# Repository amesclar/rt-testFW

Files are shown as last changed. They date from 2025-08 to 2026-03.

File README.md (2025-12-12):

# Sailing Regatta Timer - Automated Test Framework

- [Sailing Regatta Timer - Automated Test Framework](#sailing-regatta-timer---automated-test-framework)
  - [Key Features](#key-features)
  - [Measuring 12v](#measuring-12v)
  - [Flow Diagram](#flow-diagram)
  - [Board and Wiring](#board-and-wiring)
    - [Schematic](#schematic)
    - [PCB](#pcb)

## Key Features

- automated routine that exercises sailing regatta timer while monitoring buzzer activation (horn voltage)
- test board connected to computer that monitors serial port
- measures and logs horn voltage

## Measuring 12v

```text
V_out = V_in × (R2 / (R1 + R2))

R1 = 10kΩ
R2 = 5k1
```

Ratio: 2:1 (divides voltage by 3)
Output at 12V input: 4V

## Flow Diagram

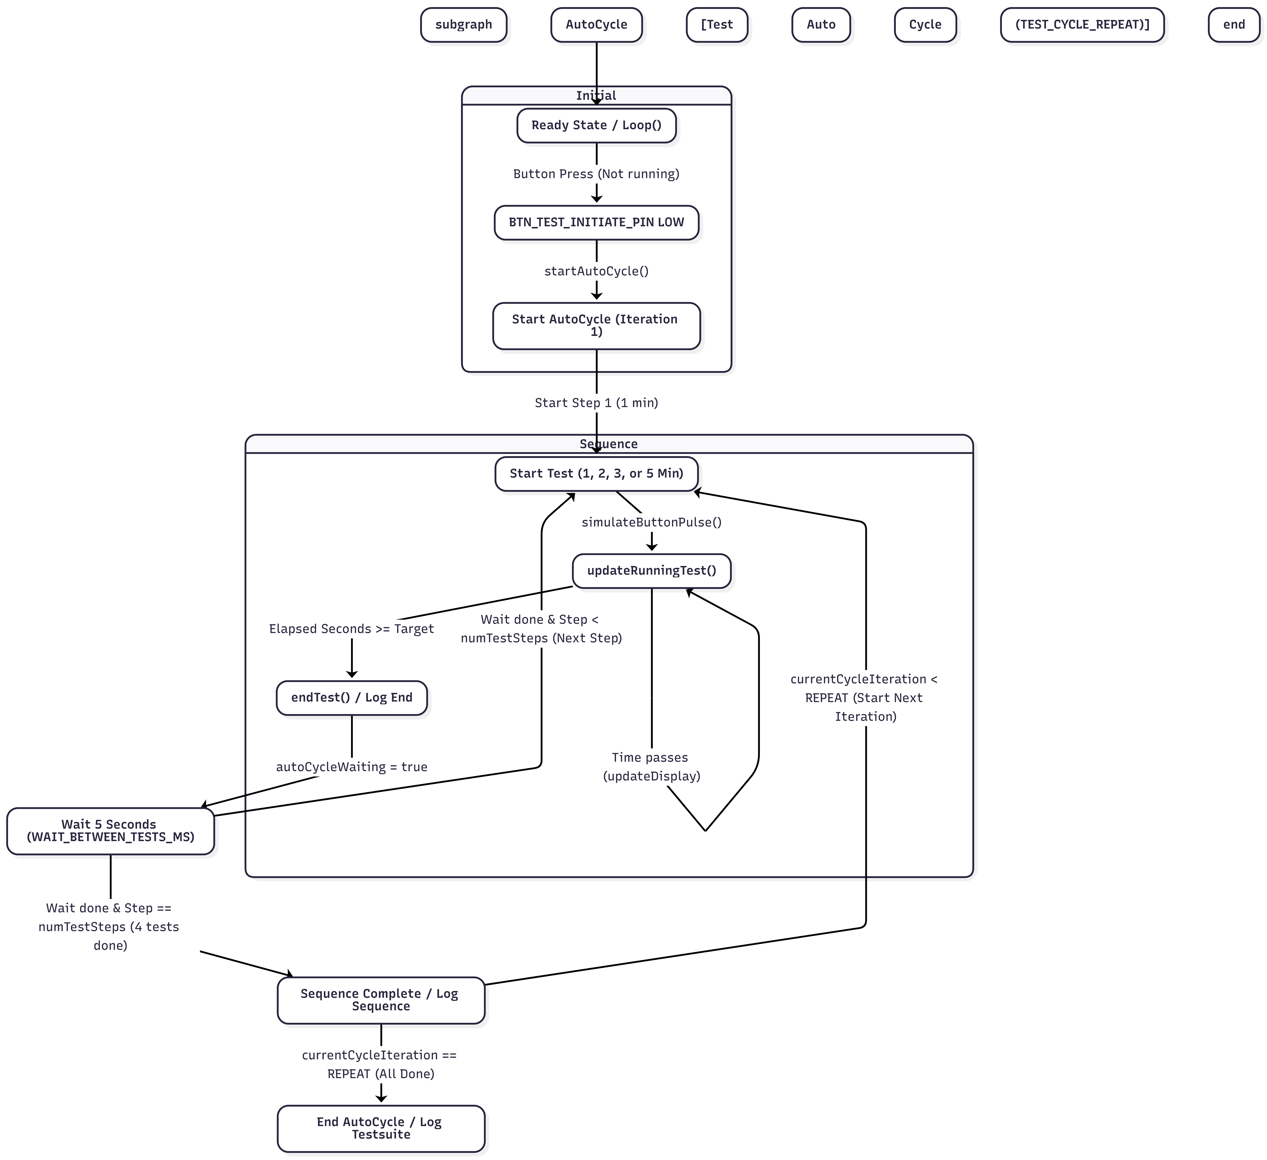
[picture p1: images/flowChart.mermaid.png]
Flow Diagram


## Board and Wiring

### Schematic

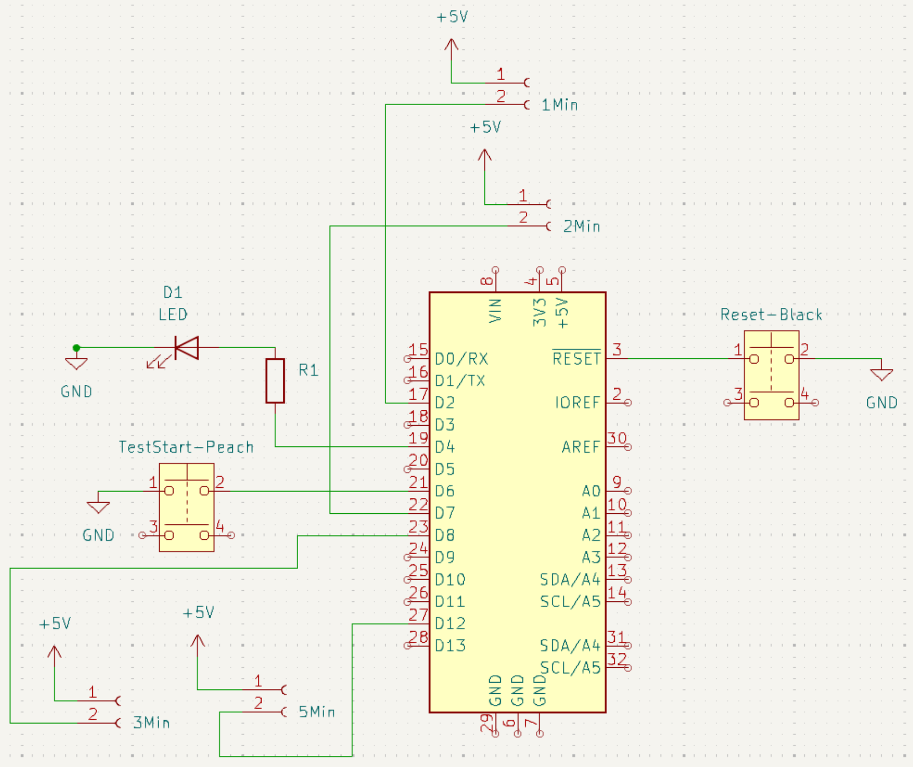
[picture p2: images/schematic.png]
Schematic


### PCB

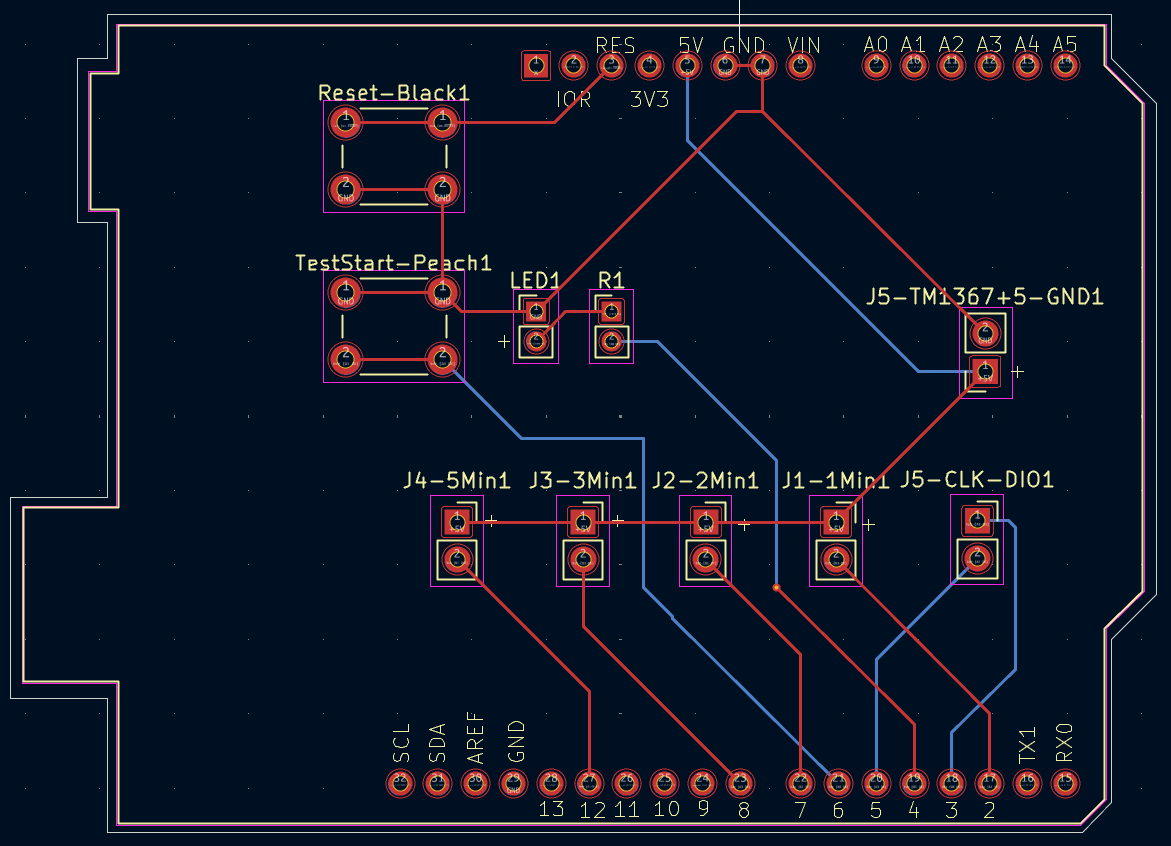
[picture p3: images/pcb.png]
PCB


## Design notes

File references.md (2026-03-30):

# References

## cli board upload

```bash

arduino-cli compile --upload -p /dev/ttyACM0 --fqbn arduino:avr:uno .
```

## dialout group (Linux)

To fix "Permission Denied" errors on serial ports:

```bash
sudo usermod -aG dialout $USER
```

*Note: You must log out and back in for this to take effect.*

### Immediate effect (current terminal only)

```bash
newgrp dialout
```

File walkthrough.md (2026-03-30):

# Walkthrough - Regatta Timer Fixes

The Regatta Timer has been updated to fix the issue where the 1-minute sequence would start automatically upon reset and run continuously. The problem was rooted in incorrect pin configuration and logic levels that didn't match the hardware and technical specifications.

## Changes Made

### 1. Pin Configuration
- Changed `pinMode` for all button pins from `INPUT` to `INPUT_PULLUP`.
- This ensures the pins are tied to 5V (logical `HIGH`) when the button is not pressed, preventing floating inputs that cause random triggers.

### 2. Button Logic Inversion
- Inverted the button press detection logic from `HIGH` to `LOW`.
- Since we are using internal pull-ups, pressing the button connects the pin to ground, resulting in a `LOW` signal.

### 3. Edge Detection
- Re-implemented state tracking using `lastBtn1`, `lastBtn2`, etc.
- The code now looks for a transition from `HIGH` (not pressed) to `LOW` (pressed).
- This ensures the system **waits for a button push** after reset and won't restart a sequence until the button is released and pressed again.

### 4. Specification Alignment
- Increased the software debounce time from 50ms to **200ms** as required by the technical specification.

## Code Comparison

```diff
-  pinMode(PIN_BTN_1MIN, INPUT);
+  pinMode(PIN_BTN_1MIN, INPUT_PULLUP);
```

```diff
-  if (btn1 == HIGH) {
-    delay(50); // Debounce
-    if (digitalRead(PIN_BTN_1MIN) == HIGH) {
+  if (lastBtn1 == HIGH && btn1 == LOW) {
+    delay(200); // Debounce
+    if (digitalRead(PIN_BTN_1MIN) == LOW) {
```

## Verification Results

### Automated Check
The code structure now correctly handles the `INPUT_PULLUP` and edge detection. The addition of state updates after the blocking `runSequence()` calls ensures that the system is ready for the next press immediately after a sequence ends, but only if the button is released first.

### Recommended Manual Tests
1. **Power On**: Verify display shows `00:00` and buzzer remains silent.
2. **Press 1min**: Verify sequence starts.
3. **Hold 1min**: Verify sequence runs once and stops, waiting for release.

---

### Previous Framework Updates
- **Output Idle State**: Output pins now idle at `HIGH` so they don't hold the SUT's `INPUT_PULLUP` pins at `LOW` by default.
- **Pulse Logic**: The `simulateButtonPulse()` function now pulses `LOW` to simulate a button press and then returns to `HIGH` after 400ms.
- **Initialization**: Updated `setup()` to set pins `HIGH` before enabling them as outputs.

---

## Responsiveness & Wiring Guidance

To ensure the system feels fast and reliable, the following timing adjustments and wiring fixes were identified:

### 1. Timing Adjustments
- **Reduced Debounce (SUT & Tester)**: Lowered from 200ms to **50ms**. This makes the buttons feel "snappy" and ensures quick manual taps are not ignored.
- **Increased Pulse Duration (Tester)**: Raised from 200ms to **400ms**. This guarantees that the Regatta Timer has enough time to detect the pulse, even with its own debouncing logic.

### 2. Physical Wiring Fix
The Regatta Timer is now configured for **Active LOW** logic with **Internal Pull-ups**.
- **Button Side**: One side of the button should go to the Pin (e.g., Pin 2) and the **other side should go to GND**, not 5V.
- **Tester Side**: **Tester GND** must be connected to **SUT GND** for the pulse signal to work.

---

## Test Framework Updates (`rt-testFW.ino`)

The test framework has also been adjusted to match the Active LOW configuration of the Regatta Timer.

### Changes Made
- **Output Idle State**: Output pins now idle at `HIGH` so they don't hold the SUT's `INPUT_PULLUP` pins at `LOW` by default.
- **Pulse Logic**: The `simulateButtonPulse()` function now pulses `LOW` to simulate a button press and then returns to `HIGH`.
- **Initialization**: Updated `setup()` to set pins `HIGH` before enabling them as outputs.

### Code Comparison (Tester)
```diff
-  digitalWrite(pin, HIGH);
-  delay(BUTTON_PULSE_DURATION_MS);
-  digitalWrite(pin, LOW);
+  digitalWrite(pin, LOW);
+  delay(BUTTON_PULSE_DURATION_MS);
---

## Baud Rate & Duration Drift Fix (2026-03-25)

The system was updated to synchronize communication at 115200 baud and minimize duration drift in longer tests.

### Changes Made
1. **Baud Rate**: Synchronized Test FW, SUT, and Serial Monitor to **115200 baud** using a consistent `BAUD_RATE` definition.
2. **Validation Reporting**: Improved `rt_data_validation.py` to extract iteration data from the test framework's logs, ensuring error messages align with the specific test sequence being run.

---

## Scrum-73: Voltage Monitoring Fix (2026-03-28)

Resolved the issue where output voltage was not being logged by addressing blocking delays and PWM signal oscillations.

### Changes Made
1. **Non-Blocking Button Pulse**: Replaced `delay(400)` with a non-blocking timer in `startButtonPulse()` and `handleButtonPulse()`. This ensures continuous voltage monitoring.
2. **Voltage Debouncing**: Added a 50ms hold-time (`VOLTAGE_HOLD_DURATION_MS`) to bridge the gaps in PWM-driven buzzer signals.
3. **Proactive Logging**: Added `VoltageStart` logging to capture the beginning of events even if the system resets during the buzzer activation.

- **5V Stimulus Test**: **PASSED**. A0 Raw jumped to ~344.
- **9V Battery Test**: **PASSED**. Connecting a 9V battery directly to the male connector pins resulted in an `A0 Raw` of **617-620** and a consistent `<testcase type="VoltageStart"/>` log.
- **Definitive Conclusion**: The Test Framework hardware, voltage divider, and software monitoring logic are **100% verified and functional**. The lack of logs during normal operation is exclusively due to the **SUT-side hardware fault** (Relay COM shorted to Ground).
- **Compilation**: Successfully compiled using `arduino-cli compile --fqbn arduino:avr:uno .`.

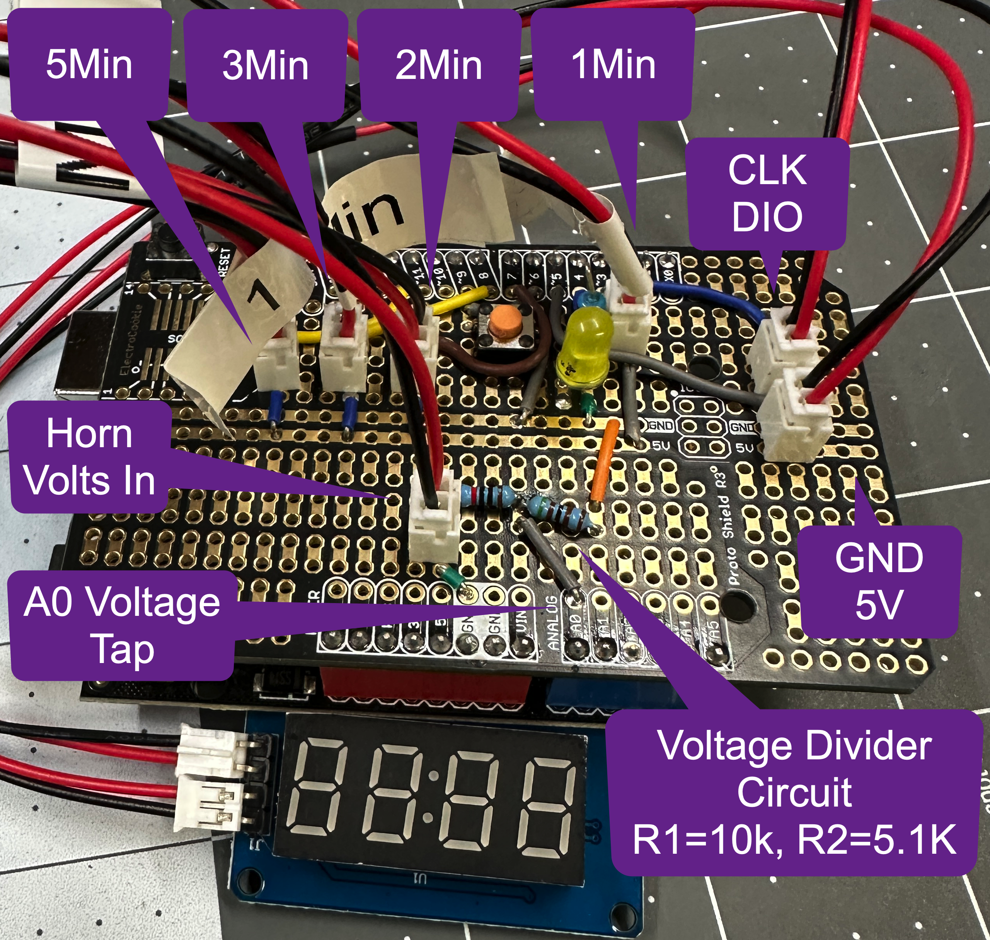
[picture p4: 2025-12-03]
images/circuitBoardProto.png

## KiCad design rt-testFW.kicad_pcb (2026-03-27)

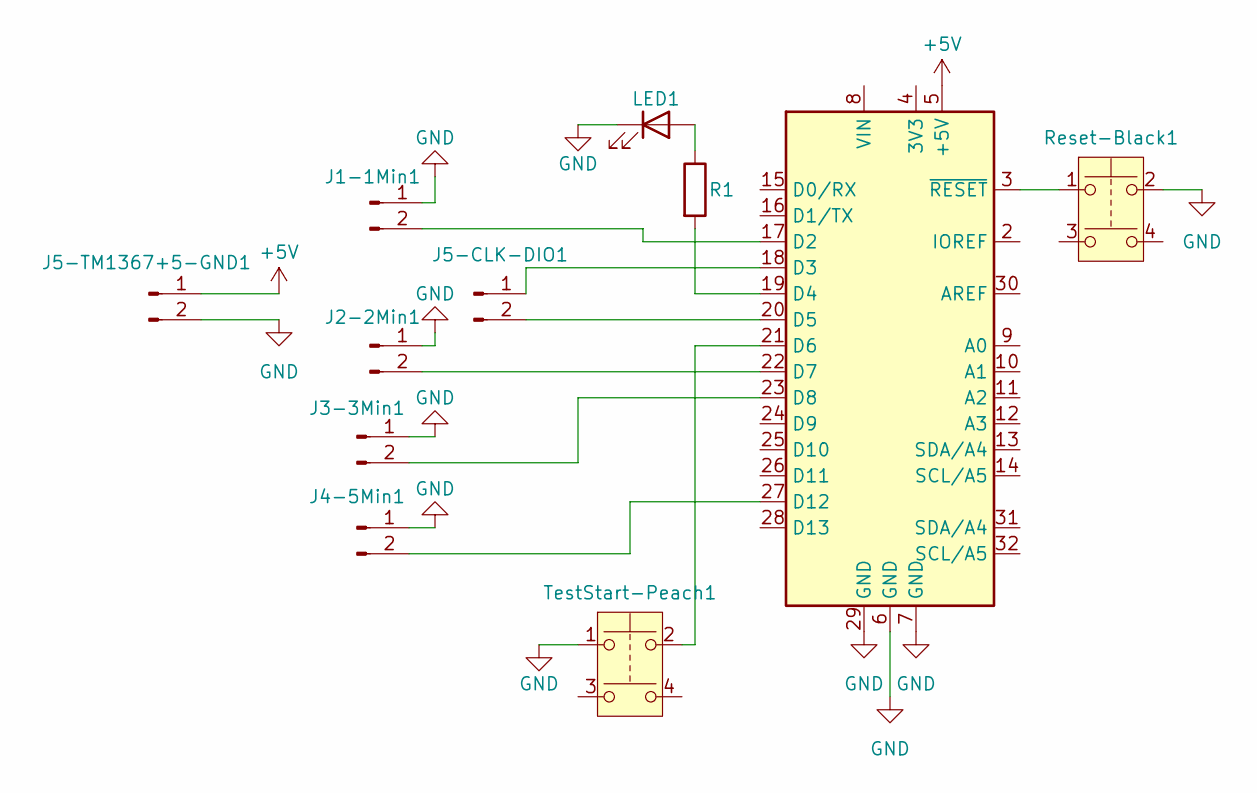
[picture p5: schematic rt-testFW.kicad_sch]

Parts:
A1: Arduino_UNO_R3
J1-1Min1, J2-2Min1, J3-3Min1, J4-5Min1, J5-CLK-DIO1, J5-TM1367+5-GND1: Conn_01x02_Male; PinSocket_1x02_P2.54mm_Vertical
LED1: LED; PinHeader_1x02_P2.00mm_Vertical
R1: R; PinHeader_1x02_P2.00mm_Vertical
Reset-Black1: SW_Push_Dual; SW_PUSH_6mm
TestStart-Peach1: SW_Push_Dual; SW_PUSH_6mm

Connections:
+5V: A1.5 (+5V), J5-TM1367+5-GND1.1
GND: A1.6 (GND), A1.7 (GND), A1.29 (GND), J1-1Min1.1, J2-2Min1.1, J3-3Min1.1, J4-5Min1.1, J5-TM1367+5-GND1.2, LED1.1 (K), Reset-Black1.2, TestStart-Peach1.1
unnamed: A1.17 (D2), J1-1Min1.2
unnamed: A1.18 (D3), J5-CLK-DIO1.1
unnamed: A1.19 (D4), R1.2
unnamed: A1.20 (D5), J5-CLK-DIO1.2
unnamed: A1.21 (D6), TestStart-Peach1.2
unnamed: A1.22 (D7), J2-2Min1.2
unnamed: A1.23 (D8), J3-3Min1.2
unnamed: A1.27 (D12), J4-5Min1.2
unnamed: A1.3 (~RESET), Reset-Black1.1
unnamed: LED1.2 (A), R1.1

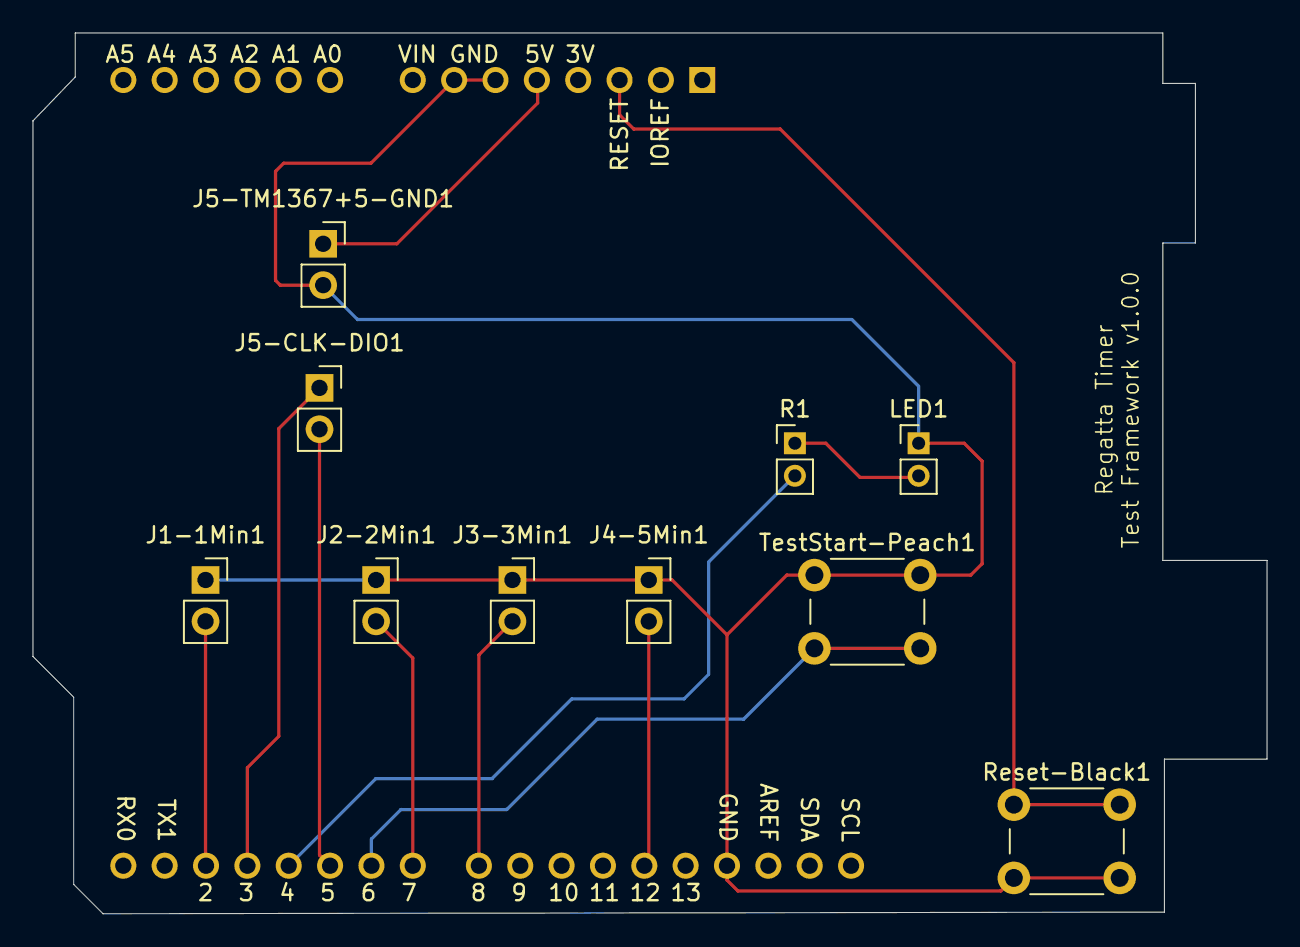
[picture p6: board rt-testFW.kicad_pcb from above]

Board: 2 copper layers, 75.8 x 54.1 mm, 11 parts (0 on the bottom side), 12 nets.

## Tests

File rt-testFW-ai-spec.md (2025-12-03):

# Regatta Timer Test Framework - Technical Specification

## Purpose
This test framework exercises the Sailing Regatta Timer by simulating button presses. Log messages are emitted for overall start, each test start and overall end. The overall test sequence is started upon button press on pin 6. A single test sequnce consists of activating the regatta timer for 1min, 2min, 3min, and 5min sequences with 5 second pause between tests. The test sequence is repeated TEST_CYCLE_REPEAT times with a default of 10.

Continuous horn voltage measurement is made on port A0 with log messages emitted when the voltage exceeds 2V. The log message should contain elapsed time (seconds), peak voltage value and duration of voltage >2V. Ignore durations shorter than 10ms. Voltage elapsed time should reset for each test (1m, 2m, 3m, 5m). The voltage split circuit consists of R1=10k ohm and R2=5.1k ohm.

TM1637 should display countdown time in MM:SS format.

Serial port speed is 9600baud.

Log messages should be JUNIT XML.

## Hardware Components

### Display
- **Type**: TM1637 4-digit 7-segment display
- **CLK Pin**: 3
- **DIO Pin**: 5
- **Format**: MM:SS (minutes:seconds with colon separator)
- **Brightness**: Maximum (0x0f)

### Monitoring Inputs
| Component | Pin | Purpose | Input type |
|---|-----|---| --- |
| Test Cycle Button | 6 | Initiate automated test cycle | INPUT_PULLUP |
| Voltage Sensor | A0 | Measure power supply voltage | Analog |

### Outputs
| Component | Pin | Purpose | Duration |
|---|-----|---| --- |
| 1min Button | 2 | start 1min test | 60 seconds |
| 2min Button | 7 | start 2min test | 120 seconds |
| 3min Button | 8 | start 3min test | 180 seconds |
| 5min Button | 12 | start 5min test | 300 seconds |
**Note, button activation duration for debouncing only not held for test duration**

### Voltage Measurement Circuit
- **Voltage Divider Configuration**:
  - R1 = 10kΩ (connected to 12V source)
  - R2 = 5.1kΩ (connected to GND)

**Voltage Calculation Formula**
```
ADC_raw = analogRead(A0)
Vout = (ADC_raw × 5.0) / 1024.0
Vin = Vout × ((R1 + R2) / R2)
Vin = Vout × 3.0
```

## Serial Communication
- **Baud Rate**: 9600
- **Format**: XML testcase fragments
- **Purpose**: Comprehensive event logging for test validation

## Operating Modes
### Automated Test Cycle Mode (ONLY MODE SUPPORTED)
- Triggered by pin 6 button press
- Sequentially simulates all four test sequences
- 5-second wait period after each test completes
- Cannot be interrupted once started

### Sequence Flow - voltage monitoring
Once per second (non-blocking) monitor voltage on pin A0 and emit log message if voltage exceeds 1V.

## Automated Test Cycle Specification
### Trigger
- **Button**: Pin 6 (Test Cycle Button)
- **Condition**: Only activates when no test is currently running
- **Behavior**: Single press initiates full cycle

### Sequence Flow - timing tests
1. **Log cycle start with voltage measurement**
2. **Simulate 1min button press** (pin 2)
   - Start 60-second test
   - Display countdown time
   - Monitor for 60 seconds
   - Log test end
3. **Wait 5 seconds**
4. **Simulate 2min button press** (pin 7)
   - Start 120-second test
   - Display countdown time
   - Monitor for 120 seconds
   - Log test end
5. **Wait 5 seconds**
6. **Simulate 3min button press** (pin 8)
   - Start 180-second test
   - Display countdown time
   - Monitor for 180 seconds
   - Log test end
7. **Wait 5 seconds**
8. **Simulate 5min button press** (pin 12)
   - Start 300-second test
   - Display countdown time
   - Monitor for 300 seconds
   - Log test end
9. **Wait 5 seconds**
10. **Log cycle end**

### Timing
- **Total Duration**: 680 seconds (11 minutes 20 seconds)
  - Test time: 60 + 120 + 180 + 300 = 660 seconds
  - Wait time: 4 × 5 = 20 seconds
- **Wait Period**: 5 seconds after EACH test (including the last one)

### Test Sequence Data Structures
```cpp
int testDurations[] = {60, 120, 180, 300};           // seconds
int testPins[] = {BTN_1MIN, BTN_2MIN, BTN_3MIN, BTN_5MIN};  // pins 2,7,8,12
int testSequenceNumbers[] = {1, 2, 3, 5};            // sequence identifiers
```

### State Management
- **autoCycleRunning**: Boolean flag indicating cycle is active
- **autoCycleStep**: Current step (0=1min, 1=2min, 2=3min, 3=5min)
- **autoCycleWaiting**: Boolean flag indicating in wait period
- **autoCycleWaitUntil**: Timestamp for end of wait period (millis)

## Event Logging (XML Format)

### Test Start Event
```xml
<testcase classname="TestStart" testsequence="[1|2|3|5]" elapsed="0" type="Start" duration="[seconds]"/>
```

### Test End Event
```xml
<testcase classname="TestEnd" testsequence="[1|2|3|5]" elapsed="[seconds]" type="End"/>
```

### Voltage Monitor
```xml
<testcase classname="VoltageMonitor" elapsed="[seconds]" voltage="[xx.xx]"/>
```

## Software Architecture
### State Variables
```cpp
// Test timing
bool testRunning = false;
unsigned long testStartMillis = 0;
unsigned long elapsedSeconds = 0;
unsigned long lastSecondUpdate = 0;
int currentTestSequence = 0;

unsigned long lastVoltageLog = 0;
#define VOLTAGE_LOG_INTERVAL 1000
#define VOLTAGE_LOG_THRESHOLD 1
```

### Main Loop Flow
1. **Check test cycle button** (pin 6)
   - If pressed and not running → start auto cycle
2. **Handle auto cycle state machine** (if active)
   - If waiting: check if wait period expired
   - If wait expired: advance step or end cycle
   - If test finished: start 5-second wait
3. **Update test timer** (if test running)
   - Update elapsed seconds every 1000ms
   - Update display countdown
   - Check if test complete

### Non-Blocking Design
- All timing uses `millis()` comparison
- No blocking delays except for button debounce (200ms)
- Wait periods use non-blocking state machine

## Behavioral Requirements

### Startup
1. Initialize serial at 9600 baud
2. Print ready message: "Regatta Timer Test Framework Ready"
3. Set display brightness to maximum
4. Display 00:00
5. Configure all pins
6. Wait for pin 6 button press to begin automated test cycle

### Auto Cycle Initiation
1. Detect pin 6 button press
2. Verify no test currently running
3. Log AutoCycleStart event
4. Set autoCycleRunning = true
5. Set autoCycleStep = 0
6. Immediately simulate first button press (1min)

### Auto Cycle State Machine
**State: Test Running**
- Let test execute normally
- Wait for test to complete

**State: Test Complete → Waiting**
- Log AutoCycleWait event with current and next step
- Set wait timer for 5 seconds

**State: Wait Period → Next Test**
- When wait expires, advance step
- If step < 4: simulate next button press
- If step >= 4: end cycle

**State: Cycle Complete**
- Log AutoCycleEnd event
- Set autoCycleRunning = false
- Return to idle state (wait for next pin 6 press)

### Libraries Required
- `TM1637Display.h` for 7-segment display control

### Memory Optimization
- Use `F()` macro for string literals in serial output
- Static arrays for test configuration
- Minimal dynamic memory allocation

### Display Format
- Leading zeros shown for proper MM:SS format
- Colon bit mask: `0b01000000`
- Format calculation: `minutes * 100 + seconds`

### Timing Accuracy
- Uses `millis()` for all timing
- 1-second resolution for tests
- 1-second resolution for voltage logging
- 5-second wait periods after tests

### Debouncing
- 200ms delay after button press detection
- Prevents multiple triggers from single press
- Applied to both manual and auto cycle buttons

## Design Principles
1. **Non-Intrusive Monitoring**: Framework observes but doesn't control the production timer
2. **Automated Testing Only**: Single button (pin 6) initiates full test cycle - no manual tests
3. **Comprehensive State Tracking**: All pin changes logged for complete visibility
4. **Deterministic Timing**: Precise 5-second gaps and test durations
5. **XML Structured Output**: Machine-parseable logs for automated validation
6. **Non-Blocking Architecture**: Concurrent monitoring and test execution
7. **Voltage Ready**: Code structure ready for voltage monitoring when hardware is implemented

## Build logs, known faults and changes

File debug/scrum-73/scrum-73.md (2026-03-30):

| Connections | Continuity (Y/N) |
| :--- | :--- |
| 1 - 2 | y |
| 2 - 3 | y |
| 3 - 4 | n |
| 4 - 5 | y |
| 5 - 6 | 10k |
| 6 - 7 | na |
| 6 - 8 | 5.1k |
| 6 - 9 | y |
| 7 - 8 | y |
| 8 - 9 | n |
| 9 - 10 | y|
| GND/left-1 | y |
| GND/right-7 | y |
| GND/left-GND/right | y |
| A0 - 10 | y |

---
<<debug sequence 1>>
step 1
Hole 4 to Resistor continuity: With everything off, measure ohms/continuity between Hole 4 (where the red wire goes) and the input leg of the 10k resistor.
```continuity buzzes```

step 2
Battery Polarity: Ensure the Positive (+) side of the 9V battery is on Pin 4 and the Negative (-) is on Pin 3.
```check```

step 3
Voltage at the holes: With the 9V battery plugged into the male pins:
Measure with your voltmeter directly from Hole 4 to Hole 3.
Do you see 9V here? If you see 0V at the holes (on the board), then the male pins are not making physical contact with the sockets.
```8.5v```

step 4
The "Golden Proof": While your d (Raw Debug) mode is running, if you touch a jumper wire from the Arduino's 5V pin directly to the top of the 10k resistor, does the A0 Raw jump to ~344?

If the "5V-to-resistor" test still works but the "9V-to-connector" test fails, the problem is 100% the physical connection at Hole 4.

What do you see when you measure voltage directly across Hole 4 and Hole 3 with the battery plugged in?

```
9:36:07.423 -> <testcase classname="VoltageMonitor" elapsedSec="0" type="VoltageStart"/>
09:36:13.190 -> --- Raw Debug ON ---
09:36:13.191 -> A0 Raw: 617
09:36:13.449 -> A0 Raw: 620
09:36:13.675 -> A0 Raw: 616
```

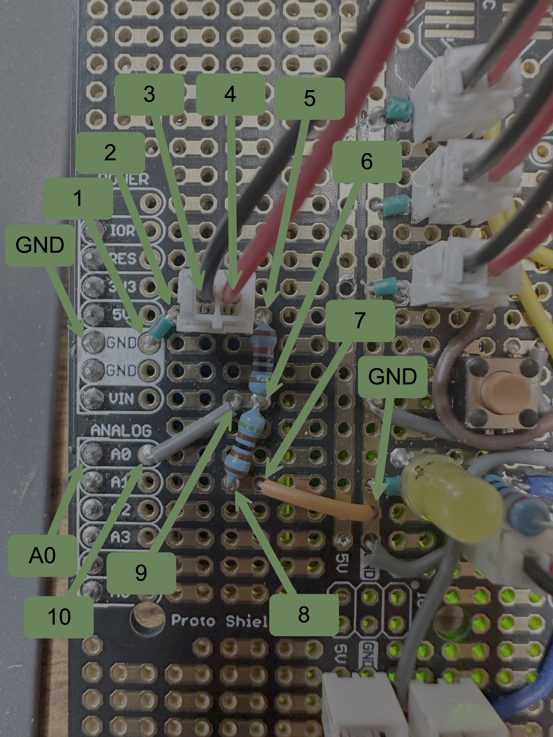
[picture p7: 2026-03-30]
debug/scrum-73/scrum-73.JPG

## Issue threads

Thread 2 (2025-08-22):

update documentation

amesclar, 2025-08-22:
readme
+ wiring no longer matches regatta timer
+ review flow diagram
+ add post processing documentation

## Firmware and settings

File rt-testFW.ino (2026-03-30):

// Gemini
// 20251202-092639
#include <Arduino.h>
#include <TM1637Display.h>

// ==========================================
// Configuration & Pin Definitions
// ==========================================

// --- Configuration ---
#define BAUD_RATE 115200
#define CLK_PIN 3
#define DIO_PIN 5

// Monitoring Inputs
#define BTN_TEST_INITIATE_PIN 6
#define VOLTAGE_SENSOR_PIN A0

// Output Pins (to simulate button presses on target device)
// Assuming Active LOW pulse to trigger target
#define BTN_1MIN_OUT_PIN 2
#define BTN_2MIN_OUT_PIN 7
#define BTN_3MIN_OUT_PIN 8
#define BTN_5MIN_OUT_PIN 12

// Voltage Measurement Configuration
// R1 = 10k, R2 = 5.1k. Spec assumes multiplier of 3.0.
#define VOLTAGE_MULTIPLIER 3.0
#define VOLTAGE_REF 5.0
#define ADC_RESOLUTION 1024.0
#define VOLTAGE_LOG_THRESHOLD 1.0
#define MIN_VOLTAGE_DURATION_MS                                                \
  10 // Minimum duration for logging a voltage event
#define VOLTAGE_HOLD_DURATION_MS                                               \
  50 // Duration to keep voltage high for PWM signals

// Test Timing Configuration
#define TEST_CYCLE_REPEAT 100      // Total iterations of the 4-test sequence
#define WAIT_BETWEEN_TESTS_MS 5000 // 5 seconds
#define BUTTON_PULSE_DURATION_MS                                               \
  400 // Duration to hold output low to simulate press
#define DEBOUNCE_DELAY_MS 50

// ==========================================
// Global Objects and Variables
// ==========================================

TM1637Display display(CLK_PIN, DIO_PIN);

// Test Sequence Data Structures (from spec)
const int testDurations[] = {60, 120, 180, 300}; // seconds
const int testPins[] = {BTN_1MIN_OUT_PIN, BTN_2MIN_OUT_PIN, BTN_3MIN_OUT_PIN,
                        BTN_5MIN_OUT_PIN};
const int testSequenceNumbers[] = {1, 2, 3, 5}; // sequence identifiers
const int numTestSteps = sizeof(testDurations) / sizeof(testDurations[0]);

// State Variables
bool autoCycleRunning = false;
int currentCycleIteration = 0; // Counts up to TEST_CYCLE_REPEAT
int autoCycleStep = 0;         // 0 to 3 (for the 4 durations)

bool testRunning = false;
unsigned long testStartMillis = 0; // Start of the current 1/2/3/5 min test
unsigned long elapsedSeconds =
    0; // Elapsed seconds within the current 1/2/3/5 min test
unsigned long lastSecondUpdate = 0;
int currentTestDurationTarget = 0;

bool autoCycleWaiting = false;
unsigned long autoCycleWaitStartMillis = 0;

// Voltage Monitoring State Variables
bool isVoltageHigh = false;
unsigned long voltageHighStartTime = 0;
unsigned long lastVoltageHighTime = 0; // Last time we saw a sample > threshold
float voltageHighPeakValue = 0.0; // Track peak voltage during the high event
bool voltageStartLogged = false; // Prevent multiple start logs for one event

// Output Pulse State
bool buttonPulseActive = false;
int buttonPulsingPin = -1;
unsigned long buttonPulseStartTime = 0;
bool debugRawMode = false; // Flag for continuous ADC debug

// ==========================================
// Forward Declarations
// ==========================================
void startAutoCycle();
void handleAutoCycleState();
void startSpecificTest(int stepIndex);
void updateRunningTest();
void endTest();
void startButtonPulse(int pin);
void handleButtonPulse();
float measureVoltage();
void updateDisplay(int secondsRemaining);

// ==========================================
// Setup
// ==========================================
void setup() {
  Serial.begin(BAUD_RATE);
  while (!Serial) {
    ; // Wait for serial port to connect.
  }

  // Initialize Pins
  pinMode(BTN_TEST_INITIATE_PIN, INPUT_PULLUP);
  pinMode(VOLTAGE_SENSOR_PIN, INPUT);

  // Initialize Outputs. Set HIGH initially because SUT is Active LOW (triggers
  // on LOW with internal pull-ups). Current logic: Idle = HIGH, Active = LOW.
  digitalWrite(BTN_1MIN_OUT_PIN, HIGH);
  pinMode(BTN_1MIN_OUT_PIN, OUTPUT);
  digitalWrite(BTN_2MIN_OUT_PIN, HIGH);
  pinMode(BTN_2MIN_OUT_PIN, OUTPUT);
  digitalWrite(BTN_3MIN_OUT_PIN, HIGH);
  pinMode(BTN_3MIN_OUT_PIN, OUTPUT);
  digitalWrite(BTN_5MIN_OUT_PIN, HIGH);
  pinMode(BTN_5MIN_OUT_PIN, OUTPUT);

  // Initialize Display
  display.setBrightness(0x0f); // Maximum brightness
  updateDisplay(0);

  Serial.println(F("Regatta Timer Test Framework Ready"));
}

// ==========================================
// Main Loop
// ==========================================
void loop() {
  unsigned long currentMillis = millis();

  // 1. Continuous Voltage Monitoring
  // This runs every loop iteration to capture duration accurately.
  float currentVoltage = measureVoltage();

  if (currentVoltage > VOLTAGE_LOG_THRESHOLD) {
    lastVoltageHighTime = currentMillis; // Update the last sample time
    if (!isVoltageHigh) {
      // Transition detected: Voltage went from LOW to HIGH
      isVoltageHigh = true;
      voltageHighStartTime = currentMillis;
      voltageHighPeakValue = currentVoltage; // Initialize peak value
      voltageStartLogged = false;
    } else {
      // Voltage is already high, update peak if current is higher
      if (currentVoltage > voltageHighPeakValue) {
        voltageHighPeakValue = currentVoltage;
      }
    }

    // Proactive "Start" log to debug resets during the buzzer event
    if (!voltageStartLogged) {
      Serial.print(F("<testcase classname=\"VoltageMonitor\" elapsedSec=\""));
      Serial.print(elapsedSeconds);
      Serial.println(F("\" type=\"VoltageStart\"/>"));
      voltageStartLogged = true;
    }
  } else if (isVoltageHigh) {
    // Current sample is LOW, but we were in HIGH state.
    // Check if the hold duration has expired (to bridge PWM gaps)
    if (currentMillis - lastVoltageHighTime >= VOLTAGE_HOLD_DURATION_MS) {
      // Transition detected: Voltage stayed LOW long enough (Event ended)
      isVoltageHigh = false;
      unsigned long totalEventDuration =
          lastVoltageHighTime - voltageHighStartTime;

      // Log the event if its effective duration meets the minimum threshold
      if (totalEventDuration >= MIN_VOLTAGE_DURATION_MS) {
        Serial.print(F("<testcase classname=\"VoltageMonitor\" elapsedSec=\""));
        Serial.print(elapsedSeconds);
        Serial.print(F("\" durationMs=\""));
        Serial.print(totalEventDuration);
        Serial.print(F("\" peakVoltage=\""));
        Serial.print(voltageHighPeakValue, 2);
        Serial.println(F("\" type=\"VoltageEnd\"/>"));
      }
    }
  }

  // 2. Check Test Initiate Button (Pin 6)
  // Edge-detection (Falling Edge) to prevent auto-start if button is stuck LOW
  static int lastButtonRead = HIGH; // Assume HIGH (not pressed) initially
  static unsigned long lastDebounceTime = 0;
  static int validButtonState = HIGH; // The stable, debounced state
  static bool waitingForRelease =
      true; // Safety: Require a HIGH state before first trigger

  int currentButtonRead = digitalRead(BTN_TEST_INITIATE_PIN);

  // If the switch changed, reset the debouncing timer
  if (currentButtonRead != lastButtonRead) {
    lastDebounceTime = currentMillis;
  }
  lastButtonRead = currentButtonRead;

  // If stable for DEBOUNCE_DELAY_MS, update the valid state
  if ((currentMillis - lastDebounceTime) > DEBOUNCE_DELAY_MS) {
    if (currentButtonRead != validButtonState) {
      validButtonState = currentButtonRead;

      // If we are waiting for release, check if we got it
      if (waitingForRelease) {
        if (validButtonState == HIGH) {
          waitingForRelease =
              false; // Button is released, ready to accept press
        }
      } else {
        // Normal operation: detected a valid state change (after release was
        // confirmed)
        if (validButtonState == LOW) {
          // Falling Edge detected (HIGH -> LOW)
          if (!autoCycleRunning) {
            startAutoCycle();
          }
        }
      }
    }
  }

  // 3. Handle Automated Cycle State Machine
  if (autoCycleRunning) {
    handleAutoCycleState();
  }

  // 4. Handle Output Pulse (Non-blocking)
  if (buttonPulseActive) {
    handleButtonPulse();
  }

  // 4. Serial Command 's' to start
  if (Serial.available() > 0) {
    char cmd = Serial.read();
    if ((cmd == 's' || cmd == 'S') && !autoCycleRunning) {
      startAutoCycle();
    }
    if (cmd == 'd' || cmd == 'D') {
      debugRawMode = !debugRawMode;
      if (debugRawMode) Serial.println(F("--- Raw Debug ON ---"));
      else Serial.println(F("--- Raw Debug OFF ---"));
    }
  }

  // 5. Raw Debug Continuous Print (Every 250ms)
  static unsigned long lastDebugPrint = 0;
  if (debugRawMode && (currentMillis - lastDebugPrint >= 250)) {
    lastDebugPrint = currentMillis;
    int raw = analogRead(VOLTAGE_SENSOR_PIN);
    Serial.print(F("A0 Raw: "));
    Serial.println(raw);
  }
}

// ==========================================
// Helper Functions
// ==========================================

// Initiates the entire multi-iteration test process
void startAutoCycle() {
  Serial.println(F("<testsuite name=\"RegattaTimerAutomatedTest\">"));
  Serial.print(F("<testcase classname=\"AutoCycleStart\" iterations=\""));
  Serial.print(TEST_CYCLE_REPEAT);
  Serial.println(F("\" type=\"CycleStart\"/>"));

  autoCycleRunning = true;
  currentCycleIteration = 1;
  autoCycleStep = 0;
  autoCycleWaiting = false;
  testRunning = false;

  // Reset voltage state for the start of a new auto cycle
  isVoltageHigh = false;
  voltageHighStartTime = 0;
  lastVoltageHighTime = 0;
  voltageHighPeakValue = 0.0;
  voltageStartLogged = false;

  // Kick off the first test immediately
  startSpecificTest(autoCycleStep);
}

// Main state machine logic for the automated sequence
void handleAutoCycleState() {
  unsigned long currentMillis = millis();

  if (testRunning) {
    // State: A specific duration test is currently executing
    updateRunningTest();

  } else if (autoCycleWaiting) {
    // State: Waiting the 5 seconds between tests
    if (currentMillis - autoCycleWaitStartMillis >= WAIT_BETWEEN_TESTS_MS) {
      autoCycleWaiting = false;
      autoCycleStep++;

      if (autoCycleStep < numTestSteps) {
        // Move to next test in current sequence (e.g., 1min done, start 2min)
        startSpecificTest(autoCycleStep);
      } else {
        // Current sequence of 4 tests done. Check iterations.
        Serial.print(
            F("<testcase classname=\"SequenceComplete\" iteration=\""));
        Serial.print(currentCycleIteration);
        Serial.println(F("\"/>"));

        if (currentCycleIteration < TEST_CYCLE_REPEAT) {
          // Reset for next iteration iteration
          currentCycleIteration++;
          autoCycleStep = 0;
          // The wait just happened. We can start immediately.
          startSpecificTest(autoCycleStep);
        } else {
          // All iterations complete
          Serial.println(
              F("<testcase classname=\"AutoCycleEnd\" type=\"CycleEnd\"/>"));
          Serial.println(F("</testsuite>"));
          autoCycleRunning = false;
          updateDisplay(0);
        }
      }
    }
  }
}

// Starts a specific duration test (1, 2, 3, or 5 min)
void startSpecificTest(int stepIndex) {
  int duration = testDurations[stepIndex];
  int seqNumber = testSequenceNumbers[stepIndex];
  int pinToPulse = testPins[stepIndex];

  Serial.print(F("<testcase classname=\"TestStart\" testsequence=\""));
  Serial.print(seqNumber);
  Serial.print(F("\" iteration=\""));
  Serial.print(currentCycleIteration);
  Serial.print(F("\" elapsed=\"0\" type=\"Start\" duration=\""));
  Serial.print(duration);
  Serial.println(F("\"/>"));

  // Initiate button press to trigger target device (Non-blocking)
  startButtonPulse(pinToPulse);

  // Reset test timers
  testRunning = true;
  testStartMillis = millis();
  lastSecondUpdate = testStartMillis;
  elapsedSeconds = 0; // Reset elapsedSeconds for the new test
  currentTestDurationTarget = duration;

  // Reset voltage peak but keep state if already high
  float vNow = measureVoltage();
  voltageHighPeakValue = (vNow > 0) ? vNow : 0.0;
  voltageStartLogged = false;

  updateDisplay(duration - elapsedSeconds);
}

// Updates the timer and display once per second during a test
void updateRunningTest() {
  unsigned long currentMillis = millis();
  if (currentMillis - lastSecondUpdate >= 1000) {
    lastSecondUpdate += 1000;
    elapsedSeconds = (currentMillis - testStartMillis) / 1000;

    int remaining = currentTestDurationTarget - elapsedSeconds;
    if (remaining < 0)
      remaining = 0;

    updateDisplay(remaining);

    if (elapsedSeconds >= currentTestDurationTarget) {
      endTest();
    }
  }
}

// Completes a specific duration test and enters waiting state
void endTest() {
  testRunning = false;
  int seqNumber = testSequenceNumbers[autoCycleStep];

  Serial.print(F("<testcase classname=\"TestEnd\" testsequence=\""));
  Serial.print(seqNumber);
  Serial.print(F("\" iteration=\""));
  Serial.print(currentCycleIteration);
  Serial.print(F("\" elapsed=\""));
  Serial.print(elapsedSeconds);
  Serial.println(F("\" type=\"End\"/>"));

  // Start the wait period
  autoCycleWaiting = true;
  autoCycleWaitStartMillis = millis();
}

// Simulates a momentary button press by pulsing an output pin LOW
// NOTE: SUT is Active LOW (with pull-ups), so we Pulse LOW from HIGH
// Starts a momentary button press pulse (Active LOW)
void startButtonPulse(int pin) {
  if (buttonPulseActive) {
    // If a pulse is already active, finish it immediately before starting a new
    // one
    digitalWrite(buttonPulsingPin, HIGH);
  }
  buttonPulsingPin = pin;
  buttonPulseActive = true;
  buttonPulseStartTime = millis();
  digitalWrite(pin, LOW);
}

// Monitors and ends the button pulse after specified duration
void handleButtonPulse() {
  if (millis() - buttonPulseStartTime >= BUTTON_PULSE_DURATION_MS) {
    digitalWrite(buttonPulsingPin, HIGH);
    buttonPulseActive = false;
  }
}

// Measures voltage on A0 using spec formula
float measureVoltage() {
  int adcRaw = analogRead(VOLTAGE_SENSOR_PIN);
  float vOut = (adcRaw * VOLTAGE_REF) / ADC_RESOLUTION;
  // Vin = Vout * ((R1 + R2) / R2) => Vin = Vout * 3.0
  float vIn = vOut * VOLTAGE_MULTIPLIER;
  return vIn;
}

// Helper to format and show time on TM1637
void updateDisplay(int secondsRemaining) {
  int minutes = secondsRemaining / 60;
  int seconds = secondsRemaining % 60;
  // 0b01000000 is the colon bitmask for TM1637
  display.showNumberDecEx(minutes * 100 + seconds, 0b01000000, true);
}

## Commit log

2025-08-22 initial iteration complete
    [rt-testFW.kicad_pcb, rt-testFW.kicad_sch]
2025-12-03 feature complete - buzzer voltage measurement
2025-12-12 final update to support tm1637 digital output
    [rt-testFW.kicad_pcb, rt-testFW.kicad_sch]
2025-12-13 added label with version to pcb
    [rt-testFW.kicad_pcb]
2025-12-15 fixed issue - immediate 1m test start
    [rt-testFW.ino]
2026-01-05 pcb-flip complete, add custom uno library
    [rt-testFW.kicad_pcb, rt-testFW.kicad_sch]
2026-01-14 pcb relayout complete
    [rt-testFW.kicad_pcb]
2026-03-25 partial commit to save work
    [rt-testFW.kicad_pcb, rt-testFW.kicad_sch]
2026-03-25 addressed 5min duration failure
    [rt-testFW.ino]
2026-03-30 voltage measurement debug complete
